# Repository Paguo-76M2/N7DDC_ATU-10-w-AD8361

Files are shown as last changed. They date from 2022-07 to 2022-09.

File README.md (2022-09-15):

# ATU-10 - The Tiny QRP Automatic Antenna Tuner with AD8361 true RMS detectors

### Official conversation group - https://groups.io/g/ATU100
### Schematic and assembly instruction by VK3PE - http://carnut.info/ATU_N7DDC/ATU-10/ATU-10_by-vk3pe_build_info/ATU-10_vk3pe_V1.2_ALL_INFO_290921.pdf

###### New in FW version 1.5 RMS
- Tuning algorithm improvement
- Minor changes

###### New in FW version 1.4 RMS
- merged code for AD8361, borrowed from N7DDC's "Symmetric" ATU
- firmware's support of original (diode) detectors is retained, to compile a FW with diodes detector - comment out the AD8361 definition declaration in the main.h file (line #30)
- the "POWER OFF" message appears on ATU shut-down after 30 minutes of idling

###### New in FW version 1.4
- The button glitches solved 
- More stability in bus transfer to OLED 
- No continious data transferring to the display 

###### New in FW version 1.3
- power meter calibrated
- compatibility with "slow Chinese" OLEDs (up to 3 seconds delay)
- reinitialise the timer after the sleep mode, keypresses should work OK now
- other fixes and enhancements

###### New in FW version 1.2  
- Display memory feature for last SWR  added 
- full automatic mode error solved.

###### New in FW version 1.1  
- the control method has been reworked, there is no more sleep mode. Now the tuner either shines on the display for 5 minutes after it is disturbed, or turns off after 30 minutes if it is not touched and the transmitter is not turned on. For these 30 minutes, the tuner constantly monitors the power supplied and instantly lights up the display when needed. The current consumption in this monitoring mode is 4 mA.
Long press on the button now turns the device on and off. 
- external control using the Icom protocol is implemented, works in both directions. That is, when the tuner button is pressed, the transceiver automatically generates a carrier for tuning and when changing from band to band, the transceiver initiates tuning by the tuner. When you press the button of external tuner control on the transceiver, the tuner is automatically run if ON or reset if OFF position.  

### Description
   The tuner is assembled in an affordable Chinese case 100x71x25 mm, the front and rear panels are made as PCB, in the same way as the main printed circuit board.
On the front panel there is a control button, a small 0.91" OLED 128 * 32 display and a USB Type C connector, used to charge the tuner's built-in battery and connect to a computer to change the firmware.



   The rear panel contains RF BNC connectors, a ground clamp and an external control interface connector that can be connected to the transceiver for more convenient control of the tuner.



   The control button has only 3 functions - a short press resets the tuner and sets all relays to their initial state, in which all reactive elements are disabled and do not affect the signal flow through the tuner, a long press causes the tuner to enter the tuning mode and a very long press for more than 5 seconds causes the firmware version to be displayed on the display.
   The display mainly shows the current transmitter power and SWR in the transmitter cable and sometimes briefly indicates the modes.
   
   The tuner is built on IM41 bistable relays, which means that a significant current is consumed by the tuner only for a short time during tuning; in rest mode, the tuner's relays retain their state for an arbitrarily long time, without consuming power.

   The built-in battery consists of two Li-Ion 14500 batteries connected in parallel. The best examples of these (SANYO) have a capacity of 800 mAh each, the worst ones are usually 400 mAh.
    The tuner has 3 power consumption modes - the operating mode, when the display indicates the parameters, lasts 5 minutes, after which the tuner falls asleep and the display turns off. You can wake him up with a short press on the button. After 30 minutes of sleep, the tuner turns off completely and you can turn it on by holding the button for a long time (more than 3 seconds).
    
   The current consumption in the operating mode is 12 mA, in the sleep mode 170 μA, in the off state 37 μA.
   


   The main microprocessor of the tuner is PIC16F18877, another PIC16F1454 processor is used as an embedded programmer. It should be flashed once using the programmer with a special firmware, after which it will be possible to change the main firmware of the tuner as many times as necessary without resorting to special means. After connecting the tuner to the computer, a new logical disk with the appropriate name will appear in the explorer, in which you can find a link to the firmware repository. To flash the tuner, it is enough to copy the firmware file to this disk, the process takes a couple of seconds and the tuner is flashed at the same moment when the file copying is completed.
   
   There is also space for two dual-color LEDs with a common anode on the board, they can be installed if you do not need an OLED display.
The right LED indicates the battery charging process, the left LED indicates the operation. In operating mode, it blinks briefly in color every three seconds, depending on the battery charge level.

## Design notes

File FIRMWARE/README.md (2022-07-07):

# Firmware files

The PIC16F1451_FW.hex is to be flashed into the PIC16F1454 chip - just once. The chip will serve as the gateway to upload firmwares into the PIC16F18877 chip. When connected to USB port of a computer - the ATU-10 will appear as an USB-disk with the link to the project's official GITHUB page. Copying HEX files to this disk will flash the PIC16F18877.

The ATU-10_*.hex files are the firmwares for the PIC16F18877 chip.
The file with the "AD8361" substring in the filename is intended for devices with the AD8361 TruPWR chips installed. If you still have diode detectors (as on the original N7DDC boards) - flash files with the "diodes" substring respectively.

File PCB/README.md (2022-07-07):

# Printed circuit board design files

The PCB is redesigned to accept:
- AD8361 TruPWR detector chips (instead of diode rectifiers)
- PIC16F18877 chip in either the UQFN-40 or the TQFP-44 packages
- PIC16F1454 chip in either the UQFN-16 or the TSSOP-14 packages
- the BNC connectors are relocated onto the rear panel PCB

The SprintLayout folder contains the source files (*.LAY6) editable/viewable with the SprintLayout6 software.
The GERBER folder contains the files necessary for PCB production (I sent them to JLCPCB, the PCBs passed all their checks and were produced successfuly).

The top layer overview:
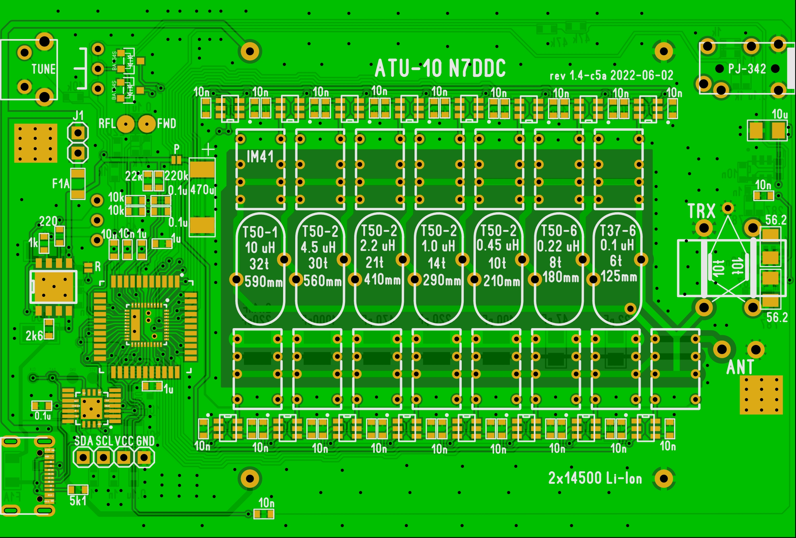
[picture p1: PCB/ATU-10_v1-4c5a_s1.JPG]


The bottom layer overview:
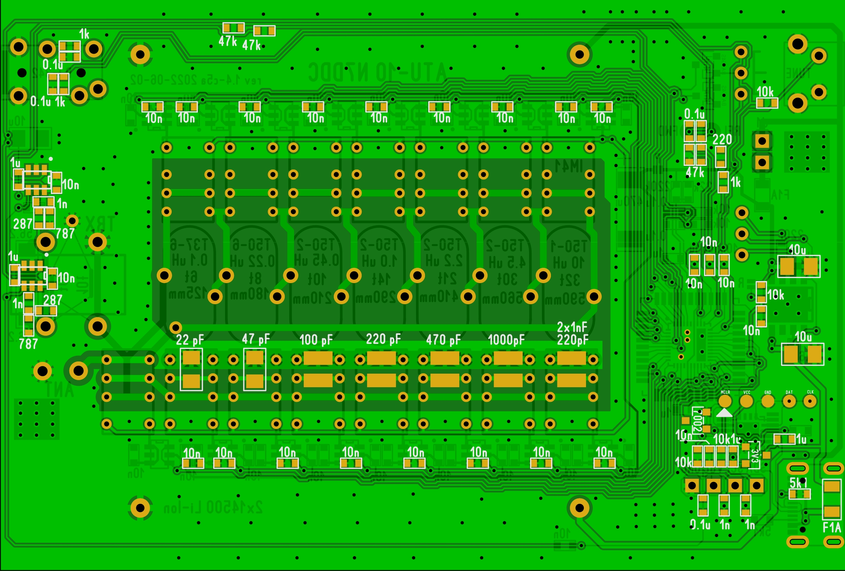
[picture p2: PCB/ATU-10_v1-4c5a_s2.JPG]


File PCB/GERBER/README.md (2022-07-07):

# Printed circuit board design files

The files necessary for PCB production (sent to JLCPCB, passed all their checks, the PCBs were produced successfuly).

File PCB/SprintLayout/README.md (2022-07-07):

# Printed circuit board design files

The source files (*.LAY6) editable/viewable with the SprintLayout6 software.

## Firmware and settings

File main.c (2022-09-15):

// ATU-10 QRP 10 watts automatic antenna tuner with AD8361 true RMS detectors
// David Fainitski, N7DDC
// 2020, 2022

#include "pic_init.h"
#include "main.h"
#include "oled_control.h"
#include "Soft_I2C.h"


// global variables
char txt[8], txt_2[8];
unsigned long Tick = 0; // ms system tick
int Voltage, Voltage_old = 0;
char btn_1_cnt = 0, btn_2_cnt = 0;
unsigned long volt_cnt = 0, watch_cnt = 0, btn_cnt = 0, off_cnt = 10, disp_cnt=10;
int PWR, SWR, SWR_ind = 0, SWR_fixed_old = 100, PWR_fixed_old = 9999;
char ind = 0, cap = 0, SW = 0;
bit Overflow, B_short, B_long, B_xlong, gre, E_short, E_long;

int Rel_Del = 8, rldl, min_for_start = 10, max_for_start = 150;
int Auto_delta = 130; // 1.3 SWR

#define Disp_time 300000 //  Time in milliseconds  0 to always on
#define Off_time  0 //1800000 //  Time in milliseconds  0 to always on

#ifdef AD8361
#define FW_VER "1.5 RMS"
#else
#define FW_VER "1.5-a"
#endif

// interrupt processing
void interupt() iv 0x0004  {
   //
   if(TMR0IF_bit) {   // Timer0   every 1ms
      TMR0IF_bit = 0;
      Tick++;
      if(disp_cnt!=0) disp_cnt--;
      if(off_cnt!=0) off_cnt--;
      TMR0L = 0xC0;   // 8_000 cycles to OF
      TMR0H = 0xE0;
      //
      if(Tick>=btn_cnt){  // every 10ms
         btn_cnt += 10;
         //
         if(GetButton | Start){
            disp_cnt = Disp_time;
            off_cnt = Off_time;
         }
         //
         if(GetButton){  //
            if(btn_1_cnt<250) btn_1_cnt++;
            if(btn_1_cnt==25) B_long = 1;  // long pressing detected
            if(btn_1_cnt==250 & OLED_PWD) B_xlong = 1;  // Xtra long pressing detected
         }
         else if(btn_1_cnt>2 & btn_1_cnt<25){
            B_short = 1;               // short pressing detected
            btn_1_cnt = 0;
         }
         else
            btn_1_cnt = 0;
         //  External interface
         if(Start){
            if(btn_2_cnt<25) btn_2_cnt++;
            if(btn_2_cnt==20 & Key_in) E_long = 1;
         }
         else if(btn_2_cnt>1 & btn_2_cnt<10){
            E_short = 1;
            btn_2_cnt = 0;
         }
         else
            btn_2_cnt = 0;
      }
   }
   return;
}


void main() {
   pic_init();
   Red = 1;
   Key_out = 1;
   gre = 1;
   oled_start();
#ifdef AD8361
   AD8361_PWD = 0; // enable AD8361
#endif
   //if(Debug) check_reset_flags();
   ADC_Init();
   Overflow = 0;
   //
   disp_cnt = Disp_time;
   off_cnt = Off_time;

   //
   rldl = Rel_Del;
   //Relay_set(0, 0, 0);
   //
   while(1) {
      if(Tick>=volt_cnt){   // every 3 second
         volt_cnt += 3000;
         Voltage_show();
      }
      //
      if(Tick>=watch_cnt){   // every 300 ms    unless power off
         watch_cnt += 300;
         watch_swr();
      }
      //
      if(Disp_time!=0 && disp_cnt==0){  // Display off
         //Disp = 0;
         OLED_PWD = 0;
      }
      //
      if(Off_time!=0 && off_cnt==0){    // Go to power off
         power_off();
      }
      //
      if(B_short){
        if(OLED_PWD) Btn_short();
         else oled_start();
      }
      if(B_long){
         if(OLED_PWD) Btn_long();
         else oled_start();
      }
      if(B_xlong){
         if(OLED_PWD) Btn_xlong();
         else oled_start();
      }
      // External interface
      if(E_short){
         if(OLED_PWD==0) oled_start();
         Btn_short();
      }
      if(E_long){
         if(OLED_PWD==0) { Ext_long(); oled_start(); }
         else Btn_long();
      }
    
  } // while(1)
} // main
//
void oled_start(){
   OLED_PWD = 1;
   //Disp = 1;
   Delay_ms(200);
   Soft_I2C_init();
   Delay_ms(10);
   oled_init();
   //
   if(gre){
      Greating();
      gre = 0;
      oled_clear();
   }
   oled_wr_str(0, 0, "PWR     W", 9);
   oled_bat();
   oled_wr_str(2, 0, "SWR      ", 9);
   oled_wr_str(0, 42, "=", 1);
   oled_wr_str(2, 42, "=", 1);
   Voltage_old = 9999;
   SWR_fixed_old = 100;
   PWR_fixed_old = 9999;
   SWR_ind = 0;
   draw_swr(SWR_ind);
   volt_cnt = Tick + 1;
   watch_cnt = Tick;
   B_short = 0; B_long = 0; B_xlong = 0, E_short = 0; E_long = 0;
   disp_cnt = Disp_time;
   off_cnt = Off_time;
   return;
}
//
void watch_swr(void){
   char peak_cnt, cnt;
   int delta = Auto_delta - 100;
   int PWR_fixed, SWR_fixed;
   //
   Delay_ms(50);
   // peak detector
   cnt = 600;
   PWR_fixed = 0;
   SWR_fixed = 0;
   for(peak_cnt=0; peak_cnt<cnt; peak_cnt++){
      get_pwr();
      if(PWR>PWR_fixed) {PWR_fixed = PWR; SWR_fixed = SWR;}
      Delay_ms(1);
   }
   //
   if(PWR_fixed>0){   // Turn on the display
      if(OLED_PWD){
         disp_cnt = Disp_time;
         off_cnt = Off_time;
      }
      else oled_start();
   };
   //
   if(PWR_fixed!=PWR_fixed_old){
      if(Overflow)
         oled_wr_str(0, 42, ">", 1);
      else
         oled_wr_str(0, 42, "=", 1);
      PWR_fixed_old = PWR_fixed;
      draw_power(PWR_fixed);
   }
    //
   if(SWR_fixed>99 && SWR_fixed!=SWR_ind){
      SWR_ind = SWR_fixed;
      if(PWR_fixed<10){
         SWR_fixed = 0;
         //SWR_ind = 0;    // Last meassured SWR on display ! not a bug
         draw_swr(SWR_ind);
         return;
      }
      else
         draw_swr(SWR_ind);
   }
   //
   if(Overflow){
      for(cnt=3; cnt!=0; cnt--){
         oled_wr_str(2, 6, "OVERLOAD ", 9);
         Delay_ms(500);
         oled_wr_str(2, 0, "         ", 9);
         Delay_ms(500);
      }
      oled_wr_str(2, 0, "SWR      ", 9);
      oled_wr_str(2, 42, "=", 1);
      draw_swr(SWR_fixed);
      Delay_ms(500);
      Overflow = 0;
   }
   //

   else if(PWR_fixed>=min_for_start && PWR_fixed<max_for_start && SWR_fixed>99) {
       if(  (SWR_fixed-SWR_fixed_old)>delta || (SWR_fixed_old-SWR_fixed)>delta  ) {
           Btn_long();
           return;
       }
   }
   //
   return;
}
//
void draw_swr(unsigned int s){
   if(s==0)
      oled_wr_str(2, 60, "0.00", 4);
   else {
      IntToStr(s, txt_2);
      txt[0] = txt_2[3];
      txt[1] = '.';
      txt[2] = txt_2[4];
      txt[3] = txt_2[5];
      //
      oled_wr_str(2, 60, txt, 4);
   }
   return;
}
//
void draw_power(unsigned int p){
   //
   if(p==0){
      oled_wr_str(0, 60, "0.0", 3);
      return;
   }
   else if(p<10){  // <1 W
      IntToStr(p, txt_2);
      txt[0] = '0';
      txt[1] = '.';
      txt[2] = txt_2[5];
   }
   else if(p<100){ // <10W
      IntToStr(p, txt_2);
      txt[0] = txt_2[4];
      txt[1] = '.';
      txt[2] = txt_2[5];
   }
   else{  // >10W
      p += 5;
      IntToStr(p, txt_2);
      txt[0] = ' ';
      txt[1] = txt_2[3];
      txt[2] = txt_2[4];
   }
   oled_wr_str(0, 60, txt, 3);
   return;
}
//
void Voltage_show(){       //  4.2 - 3.4  4200 - 3400
   get_batt();
   if(Voltage != Voltage_old) { 
      Voltage_old = Voltage; 
      oled_voltage(Voltage); 
      if(Voltage<=3800) rldl = Rel_Del + 1;
      else rldl = Rel_Del;
   }
   //
   if(Voltage>3700){
      Green = 0;
      Red = 1;
      Delay_ms(30);
      Green = 1;
      Red = 1;
   }
   else if(Voltage>3590){
      Green = 0;
      Red = 0;
      Delay_ms(30);
      Green = 1;
      Red = 1;
   }
   else { // <3.7V
      Red = 0;
      Green = 1;
      Delay_ms(30);
      Red = 1;
      Green = 1;
   }
   if(Voltage<3400){
      oled_clear();
      oled_wr_str(1, 0, "  LOW BATT ", 11);
      Delay_ms(2000);
      OLED_PWD = 0;
      power_off();
   }
   return;
}
//
void Btn_xlong(){
// v1.4m1a, moved to power_off()
//   oled_clear();
//   oled_wr_str(1, 0, " POWER OFF ", 11);
//   Delay_ms(2000);
   power_off();
   return;
}
//
void Btn_long(){
   Green = 0;
   oled_wr_str(2, 0, "TUNE     ", 9);
   Key_out = 0;
   get_SWR();
   if(SWR>99){
      tune();
      SWR_ind = SWR;
      SWR_fixed_old = SWR;
      oled_wr_str(2, 0, "SWR ", 4);
      oled_wr_str(2, 42, "=", 1);
      draw_swr(SWR_ind);
   }
   Key_out = 1;
   Green = 1;
   B_long = 0;
   E_long = 0;
   btn_1_cnt = 0;
   volt_cnt = Tick;
   watch_cnt = Tick;
   return;
}
//
void Ext_long(){
   Green = 0;
   OLED_PWD = 1;
   Key_out = 0;   //
   get_SWR();     //
   if(SWR>99)
      tune();
   Key_out = 1;   //
   SWR_ind = SWR;
   Green = 1;
   E_long = 0;
   return;
}
//
void Btn_short(){
   Green = 0;
   atu_reset();
   oled_wr_str(2, 0, "RESET    ", 9);
   Delay_ms(600);
   oled_wr_str(2, 0, "SWR  ", 5);
   oled_wr_str(2, 42, "=", 1);
   oled_wr_str(2, 60, "0.00", 4);
   SWR_fixed_old = 100;
   Delay_ms(300);
   Green = 1;
   B_short = 0;
   E_short = 0;
   btn_1_cnt = 0;
   volt_cnt = Tick;
   watch_cnt = Tick;
   return;
}
//
void Greating(){
   Green = 0;
   oled_clear();
   oled_wr_str_s(1, 0, " DESIGNED BY N7DDC", 18);
   oled_wr_str_s(3, 0, " FW VERSION ", 12);
   oled_wr_str_s(3, 12*7, FW_VER, strlen(FW_VER)); // v1.4m1a
   Delay_ms(3000);
   while(GetButton) asm NOP;
   Green = 1;
   return;
}
//
void atu_reset(){
   ind = 0;
   cap = 1;
   SW = 0;
   Relay_set(ind, cap, SW);
   return;
}
//
void Relay_set(char L, char C, char I){
   L_010 = ~L.B0;
   L_022 = ~L.B1;
   L_045 = ~L.B2;
   L_100 = ~L.B3;
   L_220 = ~L.B4;
   L_450 = ~L.B5;
   L_1000 = ~L.B6;
   //
   C_22 = ~C.B0;
   C_47 = ~C.B1;
   C_100 = ~C.B2;
   C_220 = ~C.B3;
   C_470 = ~C.B4;
   C_1000 = ~C.B5;
   C_2200 = ~C.B6;
   //
   C_sw = I;
   //
   Rel_to_gnd = 1;
   Vdelay_ms(rldl);
   Rel_to_gnd = 0;
   Delay_us(10);
   Rel_to_plus_N = 0;
   Vdelay_ms(rldl);
   Rel_to_plus_N = 1;
   Vdelay_ms(rldl);
   //
   L_010 = 0;
   L_022 = 0;
   L_045 = 0;
   L_100 = 0;
   L_220 = 0;
   L_450 = 0;
   L_1000 = 0;
   //
   C_22 = 0;
   C_47 = 0;
   C_100 = 0;
   C_220 = 0;
   C_470 = 0;
   C_1000 = 0;
   C_2200 = 0;
   //
   C_sw = 0;
   return;
}
//
void power_off(void){
   char btn_cnt;
   // Disable interrupts
   GIE_bit = 0;
   T0EN_bit = 0;
   TMR0IF_bit = 0;
   IOCIE_bit = 1;
   IOCBF5_bit = 0;
   IOCBN5_bit = 1;
   // Power saving
#ifdef AD8361
   AD8361_PWD = 1; // disable AD8361
#endif
   // v1.4m1a, say good-bye nicely
   if(OLED_PWD==0) { OLED_PWD = 1; Delay_ms(200); Soft_I2C_init(); Delay_ms(10); oled_init(); }
   oled_clear();
   oled_wr_str(1, 0, " POWER OFF ", 11);
   Delay_ms(2000);
   OLED_PWD = 0;
   RED = 1;
   Green = 1;
   //
   btn_cnt = 0;
   while(1){
      if(btn_cnt==0){ Delay_ms(100); IOCBF5_bit = 0; asm sleep; }
      asm NOP;
      Delay_ms(100);
      if(GetButton) btn_cnt++;
      else btn_cnt = 0;
      if(btn_cnt>15) break;
   }
   // Enable interrupts
   IOCIE_bit = 0;
   IOCBN5_bit = 0;
   IOCBF5_bit = 0;
   T0EN_bit = 1;
   GIE_bit = 1;
   // Return to work
#ifdef AD8361
   AD8361_PWD = 0; // enable AD8361
#endif
   gre = 1;
   oled_start();
   while(GetButton){asm NOP;}
   btn_1_cnt = 0;
   btn_cnt = Tick;
   return;
}
//
void check_reset_flags(void){
   char i = 0;
   if(STKOVF_bit){oled_wr_str_s(0,  0, "Stack overflow",  14); i = 1;}
   if(STKUNF_bit){oled_wr_str_s(1,  0, "Stack underflow", 15); i = 1;}
   if(!nRWDT_bit){oled_wr_str_s(2,  0, "WDT overflow",    12); i = 1;}
   if(!nRMCLR_bit){oled_wr_str_s(3, 0, "MCLR reset  ",    12); i = 1;}
   if(!nBOR_bit){oled_wr_str_s(4,   0, "BOR reset  ",     12); i = 1;}
   if(i){
      Delay_ms(5000);
      oled_clear();
   }
   return;
}

#ifndef AD8361
//
int correction(int input) {
     input *= 2;
     //
     if(input <= 543) input += 256;
     else if(input <= 791) input += 274;
     else if(input <= 1225) input += 288;
     else if(input <= 1991) input += 286;
     else if(input <= 2766) input += 288;
     else if(input <= 3970) input += 260;
     else if(input <= 5100) input += 250;
     else  input += 240;
     //
     return input;
}
//
#endif

int get_reverse(void){
   unsigned int v;
   unsigned long d;
   ADC_Init_Advanced(_ADC_INTERNAL_VREFL | _ADC_INTERNAL_FVRH1);
   Delay_us(100);
   v = ADC_Get_Sample(REV_input);
   if(v==1023){
      ADC_Init_Advanced(_ADC_INTERNAL_VREFL | _ADC_INTERNAL_FVRH2);
      Delay_us(100);
      v = ADC_Get_Sample(REV_input) * 2;
   }
   if(v==2046){
      ADC_Init_Advanced(_ADC_INTERNAL_VREFL | _ADC_INTERNAL_VREFH);
      Delay_us(100);
      v = ADC_Get_Sample(REV_input);
      if(v==1023) Overflow = 1;
      get_batt();
      d = (long)v * (long)Voltage;
      d = d / 1024;
      v = (int)d;
   }
   return v;
}
//
int get_forward(void){
   unsigned int v;
   unsigned long d;
   ADC_Init_Advanced(_ADC_INTERNAL_VREFL | _ADC_INTERNAL_FVRH1);
   Delay_us(100);
   v = ADC_Get_Sample(FWD_input);
   if(v==1023){
      ADC_Init_Advanced(_ADC_INTERNAL_VREFL | _ADC_INTERNAL_FVRH2);
      Delay_us(100);
      v = ADC_Get_Sample(FWD_input) * 2;
   }
   if(v==2046){
      ADC_Init_Advanced(_ADC_INTERNAL_VREFL | _ADC_INTERNAL_VREFH);
      Delay_us(100);
      v = ADC_Get_Sample(FWD_input);
      if(v==1023) Overflow = 1;
      get_batt();
      d = (long)v * (long)Voltage;
      d = d / 1024;
      v = (int)d;
   }
   return v;
}
//
void get_pwr(){
   long Forward, Reverse;
   float p;
   //
   Forward = get_forward();
   Reverse = get_reverse();
   //
#ifdef AD8361
   p = Forward / 7.22;
   p = p * 110.0;
   p = p / 1000.0;
   p = p * p;
   p = p / 5;
   p += 0.5;
#else
   p = correction(Forward);
   p = p * 5 / 1000;
   p = p / 1.414;
   p = p * p;
   p = p / 5;
   p += 0.5;
#endif
   PWR = p;
   //
   if(PWR>0){
      if(OLED_PWD){
         disp_cnt = Disp_time;
         off_cnt = Off_time;
      }
      else oled_start();
   }
   //
   if(Reverse >= Forward)
      Forward = 999;
   else {
      Forward = ((Forward + Reverse) * 100) / (Forward - Reverse);
      if(Forward>999) Forward = 999;
   }
   //
   SWR = Forward;
   return;
}
//
void get_swr(){
   unsigned int pwr_cnt = 300, tuneoff_cnt = 300;
   unsigned int PWR_max = 0;
   get_pwr();
   while(PWR<min_for_start || PWR>max_for_start){   // waiting for good power
      if(B_short){
         Btn_short();
         SWR = 0;
         break;
      }
      if(B_xlong){
         //Btn_xlong();
         SWR = 0;
         break;
      }
      //
      get_pwr();
      if(pwr_cnt>0){
          pwr_cnt --;
          if(PWR>PWR_max)
              PWR_max = PWR;
      }
      else {
         if(PWR_max!=PWR_fixed_old) draw_power(PWR_max);
         PWR_fixed_old = PWR_max;
         PWR_max = 0;
         pwr_cnt = 300;
         if(tuneoff_cnt>0) tuneoff_cnt--;
         else { SWR = 0; break; }
         Delay_ms(1);
      }
   }
   //  good power
   return;
}
//
void get_batt(void){
   ADC_Init_Advanced(_ADC_INTERNAL_VREFL | _ADC_INTERNAL_FVRH1);
   Delay_us(100);
   Voltage = ADC_Get_Sample(Battery_input) * 11;
   return;
}
//
void tune(void){
   int SWR_mem;
   char cap_mem, ind_mem;
   subtune();
   get_SWR();
   if(SWR<=120) return;
   SWR_mem = SWR;
   cap_mem = cap;
   ind_mem = ind;
   if(SW==1) SW = 0;
   else SW = 1;
   subtune();
   get_SWR();
   if(SWR>SWR_mem){
      if(SW==1) SW = 0;
      else SW = 1;
      cap = cap_mem;
      ind = ind_mem;
      Relay_set(ind, cap, SW);
      Delay_ms(5);
      get_SWR();
   }
   if(SWR<=120) return;
   sharp_tune();
   get_SWR();
   return;
}
//
void subtune(void){
   cap = 0;
   ind = 0;
   Relay_set(ind, cap, SW);
   delay_ms(50);
   get_SWR();
   if(SWR<=120) return;
   coarse_tune();
   get_SWR();
   if(SWR<=120) return;
   sharp_tune();
   return;
}
//
void coarse_tune(void){
   int SWR_mem1 = 10000, SWR_mem2 = 10000, SWR_mem3 = 10000;
   char ind_mem1, cap_mem1, ind_mem2, cap_mem2, ind_mem3, cap_mem3;
   coarse_cap();
   coarse_ind();
   get_SWR();
   if(SWR<=120) return;
   SWR_mem1 = SWR;
   ind_mem1 = ind;
   cap_mem1 = cap;
   if(cap<=2 & ind<=2){
      cap = 0;
      ind = 0;
      Relay_set(ind, cap, SW);
      Delay_ms(5);
      coarse_ind();
      coarse_cap();
      get_SWR();
      if(SWR<=120) return;
      SWR_mem2 = SWR;
      ind_mem2 = ind;
      cap_mem2 = cap;
   }
   if(cap<=2 & ind<=2){
      cap = 0;
      ind = 0;
      Relay_set(ind, cap, SW);
      Delay_ms(5);
      coarse_ind_cap();
      get_SWR();
      if(SWR<=120) return;
      SWR_mem3 = SWR;
      ind_mem3 = ind;
      cap_mem3 = cap;
   }
   if(SWR_mem1<=SWR_mem2 & SWR_mem1<=SWR_mem3){
      cap = cap_mem1;
      ind = ind_mem1;
   }
   else if(SWR_mem2<=SWR_mem1 & SWR_mem2<=SWR_mem3){
      cap = cap_mem2;
      ind = ind_mem2;
   }
   else if(SWR_mem3<=SWR_mem1 & SWR_mem3<=SWR_mem2){
      cap = cap_mem3;
      ind = ind_mem3;
   }
   return;
}
//
void coarse_ind_cap(void){
   int SWR_mem;
   char ind_mem;
   ind_mem = 0;
   get_swr();
   SWR_mem = SWR / 10;
   for(ind=1; ind<64; ind*=2){
      Relay_set(ind, ind, SW);
      Delay_ms(5);
      get_swr();
      SWR = SWR/10;
      if(SWR<=SWR_mem){
         ind_mem = ind;
         SWR_mem = SWR;
      }
      else
         break;
   }
   ind = ind_mem;
   cap = ind_mem;
   Relay_set(ind, cap, SW);
   Delay_ms(5);
   return;
}
//
void coarse_cap(void){
   int SWR_mem;
   char cap_mem;
   cap_mem = 0;
   get_swr();
   SWR_mem = SWR / 10;
   for(cap=1; cap<64; cap*=2){
      Relay_set(ind, cap, SW);
      Delay_ms(5);
      get_swr();
      SWR = SWR/10;
      if(SWR<=SWR_mem){
         cap_mem = cap;
         SWR_mem = SWR;
      }
      else
         break;
   }
   cap = cap_mem;
   Relay_set(ind, cap, SW);
   Delay_ms(5);
   return;
}
//
void coarse_ind(void){
   int SWR_mem;
   char ind_mem;
   ind_mem = 0;
   get_swr();
   SWR_mem = SWR / 10;
   for(ind=1; ind<64; ind*=2){
      Relay_set(ind, cap, SW);
      Delay_ms(5);
      get_swr();
      SWR = SWR/10;
      if(SWR<=SWR_mem){
         ind_mem = ind;
         SWR_mem = SWR;
      }
      else
         break;
   }
   ind = ind_mem;
   Relay_set(ind, cap, SW);
   Delay_ms(5);
   return;
}
//
void sharp_tune(void){
   if(cap>=ind){
      sharp_cap();
      sharp_ind();
   }
   else{
      sharp_ind();
      sharp_cap();
   }
   return;
}
//
void sharp_cap(void){
   int SWR_mem;
   char step, cap_mem;
   cap_mem = cap;
   step = cap / 10;
   if(step==0) step = 1;
   get_SWR();
   SWR_mem = SWR;
   cap += step;
   Relay_set(ind, cap, SW);
   Delay_ms(5);
   get_SWR();
   if(SWR<=SWR_mem){
      SWR_mem = SWR;
      cap_mem = cap;
      for(cap+=step; cap<=(127-step); cap+=step){
         Relay_set(ind, cap, SW);
         Delay_ms(5);
         get_SWR();
         if(SWR<=SWR_mem){
            cap_mem = cap;
            SWR_mem = SWR;
            step = cap / 10;
            if(step==0) step = 1;
         }
         else
            break;
      }
   }
   else{
      SWR_mem = SWR;
      for(cap-=step; cap>=step; cap-=step){
         Relay_set(ind, cap, SW);
         Delay_ms(5);
         get_SWR();
         if(SWR<=SWR_mem){
            cap_mem = cap;
            SWR_mem = SWR;
            step = cap / 10;
            if(step==0) step = 1;
         }
         else
            break;
      }
   }
   cap = cap_mem;
   Relay_set(ind, cap, SW);
   Delay_ms(5);
   return;
}
//
void sharp_ind(void){
   int SWR_mem;
   char step, ind_mem;
   ind_mem = ind;
   step = ind / 10;
   if(step==0) step = 1;
   get_SWR();
   SWR_mem = SWR;
   ind += step;
   Relay_set(ind, cap, SW);
   Delay_ms(5);
   get_SWR();
   if(SWR<=SWR_mem){
      SWR_mem = SWR;
      ind_mem = ind;
      for(ind+=step; ind<=(127-step); ind+=step){
         Relay_set(ind, cap, SW);
         Delay_ms(5);
         get_SWR();
         if(SWR<=SWR_mem){
            ind_mem = ind;
            SWR_mem = SWR;
            step = ind / 10;
            if(step==0) step = 1;
         }
         else
            break;
      }
   }
   else{
      SWR_mem = SWR;
      for(ind-=step; ind>=step; ind-=step){
         Relay_set(ind, cap, SW);
         Delay_ms(5);
         get_SWR();
         if(SWR<=SWR_mem){
            ind_mem = ind;
            SWR_mem = SWR;
            step = ind / 10;
            if(step==0) step = 1;
         }
         else
            break;
      }
   }
   ind = ind_mem;
   Relay_set(ind, cap, SW);
   Delay_ms(5);
   return;
}
//

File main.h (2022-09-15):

void pic_init(void);
void Btn_long(void);
void Btn_short(void);
void Btn_xlong(void);
void check_reset_flags(void);
void Voltage_show(void);
void Relay_set(char, char, char);
int get_reverse(void);
int get_forward(void);
void get_pwr(void);
void get_swr(void);
void get_batt(void);
void watch_swr(void);
void coarse_cap(void);
void tune(void);
void subtune(void);
void coarse_tune(void);
void coarse_cap(void);
void coarse_ind(void);
void coarse_ind_cap(void);
void sharp_tune(void);
void sharp_cap(void);
void sharp_ind(void);
int correction(int);
void atu_reset(void);
void draw_swr(unsigned int);
void draw_power(unsigned int);
void oled_start(void);
void power_off(void);
void Greating(void);
void Ext_long(void);

#define AD8361        // adds support for TI's AD8361 TruPwr RF-detector

#define ON 1
#define OFF 0
#define INT GIE_bit
#define Battery_input 9
#define FWD_input 8
#define REV_input 10
#define _AD_High ADFVR0_bit=0;ADFVR1_bit=1;
#define _AD_Low  ADFVR0_bit=1;ADFVR1_bit=0;
#define Key_out LATD2_bit
#define Key_in PORTD.B2
#define Start_out LATD1_bit
#define Start ~PORTD.B1

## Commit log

2022-07-07 v1.4 RMS
    [ATU-10_v1-4c5a_jlcpcb-[ATU-10].DRL, ATU-10_v1-4c5a_jlcpcb-[ATU-10]_copper_bottom.gbr, ATU-10_v1-4c5a_jlcpcb-[ATU-10]_copper_top.gbr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]
2022-09-15 v1.5 RMS
    [ATU-10.cfg]
